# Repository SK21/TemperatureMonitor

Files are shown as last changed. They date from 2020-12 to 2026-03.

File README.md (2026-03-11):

# TemperatureMonitor

Temperature Monitor reads temperatures from DS18B20 sensors in grain bins. It consists of a server and multiple clients (controlboxes). The server is installed on a PC on the LAN. Each controlbox sends data over wifi to the server. On startup if a network connection can't be made a web page is started at 192.168.4.1 . 
  
Hookup Schematic:
 

TMarduino can use a DS2482 1-Wire Master. It is a device to connect to 1-Wire networks for improved performance. A DS2482 breakout is available at https://www.artekit.eu/products/breakout-boards/io/ak-ds2482s-100/

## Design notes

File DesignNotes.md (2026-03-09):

# BinTemps C# App - Design Notes

## Overview

A new C# desktop application to replace the VB6 server. Communicates over WiFi (UDP) with ESP8266-based bin temperature modules (existing TM13 hardware). Firmware is complete.

---

## Technology Stack

| Layer | Choice |
|---|---|
| UI | WinForms (.NET Framework 4.8) |
| Database | SQLite via EF6 (`EntityFramework` + `System.Data.SQLite`) |
| Charts | OxyPlot (`OxyPlot.WindowsForms`) |
| Network | UDP (`System.Net.Sockets.UdpClient`) |
| Async | async/await + CancellationToken |
| Config | Newtonsoft.Json |

---

## Project Structure

```
BinTempsApp/
├── BinTempsApp.slnx
└── BinTempsApp/
    ├── BinTempsApp.csproj        # .NET Framework 4.8 WinForms
    ├── Program.cs
    ├── MainForm.cs               # Main MDI or tabbed shell
    ├── Network/
    │   ├── UdpServer.cs          # Bind, heartbeat broadcast, receive loop
    │   └── PacketParser.cs       # Parse raw bytes into typed packets
    ├── Models/
    │   ├── Module.cs
    │   ├── Sensor.cs
    │   ├── TemperatureRecord.cs
    │   └── Packet.cs
    ├── Data/
    │   ├── AppDbContext.cs       # EF6 DbContext
    │   └── Migrations/
    ├── Services/
    │   ├── TemperatureService.cs
    │   └── SensorService.cs
    └── Forms/
        ├── DashboardForm.cs      # Live module/connection status
        ├── TemperatureForm.cs    # Temperature data sheet
        ├── ChartForm.cs          # OxyPlot trend charts
        ├── BinMapForm.cs         # Visual bin layout
        └── SettingsForm.cs       # App settings, sensor management
```

---

## UDP Protocol (PGNs)

All packets begin with two fixed bytes: type identifier and protocol version (120).
Temperature lo/hi = raw DS18B20 16-bit value (signed, divide by 16.0 for Celsius).

### App to Module

#### 30820 - Heartbeat (broadcast, 3 bytes)
| Byte | Value |
|---|---|
| 0 | 100 |
| 1 | 120 |
| 2 | CRC |

Sent by app on a regular interval (e.g. every 30 seconds) to the subnet broadcast address. Modules track the last heartbeat time. If no heartbeat is received for 90 seconds (~3 missed), the module attempts WiFi reconnect and re-announces itself with PGN 30831.

#### 30821 - Command (app to module)
| Byte | Field |
|---|---|
| 0 | 101 |
| 1 | 120 |
| 2 | Module ID (0x00 = global broadcast) |
| 3 | Command byte |
| 4 | CRC |

Command byte bits:
- bit 0 = send sensor temps (30830)
- bit 1 = send module description (30831)

Module ID 0x00 = global broadcast — all modules respond.
Module ID 0x01-0xFE = targeted, module responds immediately.
Module ID 0xFF = reserved.

#### 30822 - Set Module Description (app to module)
| Byte | Field |
|---|---|
| 0 | 102 |
| 1 | 120 |
| 2-7 | Module MAC (6 bytes, used to identify target) |
| 8 | New Module ID |
| 9-18 | New Description (10 bytes, UTF-8) |
| 19 | CRC |

#### 30823 - Set Sensor User Data (app to module)
| Byte | Field |
|---|---|
| 0 | 103 |
| 1 | 120 |
| 2 | Module ID |
| 3-10 | Sensor serial / ROM code (8 bytes) |
| 11 | New user data byte 0 |
| 12 | New user data byte 1 |
| 13 | CRC |

---

### Module to App

#### 30830 - Temperature Data
| Byte | Field |
|---|---|
| 0 | 110 |
| 1 | 120 |
| 2 | Module ID |
| 3-10 | Sensor serial / ROM code (8 bytes) |
| 11 | Temp lo (raw DS18B20 low byte) |
| 12 | Temp hi (raw DS18B20 high byte) |
| 13 | Sensor user data byte 0 |
| 14 | Sensor user data byte 1 |
| 15 | Count of sensors remaining |
| 16 | CRC |

One packet per sensor. Sensor user data (bin/cable/sensor encoding) is included inline with each reading. Count of sensors remaining decrements to 0 on the final packet.

#### 30831 - Module Description
| Byte | Field |
|---|---|
| 0 | 111 |
| 1 | 120 |
| 2 | Module ID (0 = unregistered) |
| 3-8 | Module MAC (6 bytes) |
| 9-18 | Module description (10 bytes, UTF-8) |
| 19-20 | InoID / firmware version (uint16, lo byte first) |
| 21 | CRC |

Sent unsolicited once on startup/reconnect. If module ID = 0, server knows it is unregistered and prompts user to assign an ID via 30822. Also sent in response to 30821 command bit 1. The InoID field allows the app to detect outdated firmware.

---

## Sensor User Data Encoding

16-bit value stored in DS18B20 EEPROM bytes 2-3 (unchanged from original firmware):
```
[15:8] = Bin ID    [7:4] = Cable ID    [3:0] = Sensor number
```

```csharp
public static (byte Bin, byte Cable, byte Sensor) DecodeUserData(ushort raw)
    => ((byte)(raw >> 8), (byte)((raw >> 4) & 0xF), (byte)(raw & 0xF));
```

---

## WiFi Provisioning

Modules are physically installed in the field (grain bins), often too far from the server PC to reliably connect to the module's soft-AP hotspot. Provisioning is therefore done via a smartphone brought to the bin.

### Provisioning Flow
1. Module boots with no stored credentials (or fails to connect after N attempts)
2. Module starts a soft-AP named `BinTemps-<MAC>` and serves a simple config web page
3. Technician walks to the bin with a smartphone, connects to the module's AP
4. Browser opens the config page, technician enters SSID + password
5. Module saves credentials to EEPROM and reboots into station mode
6. On reconnect, module sends unsolicited 30831 — the C# app handles registration from there

The C# app has no role in provisioning. It only becomes involved once the module is on the network.

---

## Module Identity & Discovery

- **MAC address** is the stable unique key for each module (factory-burned, never changes).
- **Module ID** (1 byte, 1-254) is assigned by the server via 30822 and stored in module EEPROM.
- **ID = 0** means unregistered.

### New Module Flow
1. Module powers up with ID = 0
2. Module sends one unsolicited 30831 (MAC + ID=0)
3. Server detects ID=0, prompts user to assign name/ID
4. Server sends 30822 using MAC as key, assigns new ID + description
5. Module stores ID in EEPROM, uses it from then on
6. If 30822 is lost, the next global 30821 (broadcast) will re-trigger the 30831 from the module

### Reconnect Flow
1. Module receives no heartbeat for 90 seconds
2. If WiFi is disconnected, module attempts reconnect
3. On reconnect, `udp.begin(port)` is called and module sends unsolicited 30831 (with its assigned ID)
4. If WiFi is still connected but server went quiet, module re-sends 30831 to re-announce itself
5. Server knows the module is back online

---

## Database Schema (SQLite)

```
Modules      - MacAddress (PK), ModuleId, Name, LastKnownIp, LastSeen, Status
Sensors      - RomCode (PK), ModuleMac (FK), BinId, CableId, SensorNum, Enabled, Offset, MaxTemp, Label
Records      - Id, RomCode (FK), Temperature, Timestamp
Bins         - Id, Name, Description, Rows, Cols
BinSensorMap - BinId, SensorRomCode, Row, Col
Settings     - Key, Value
```

---

## C# App — UDP Notes

- App binds to `0.0.0.0` on port 1600 to receive UDP from any module on the network
- Heartbeat (30820) and commands (30821) are sent to the subnet broadcast address
- Module responses (30830, 30831) arrive from the module's IP — use `UdpReceiveResult.RemoteEndPoint` to track module IPs
- `UdpClient` must have `EnableBroadcast = true` and `Client.SetSocketOption(SocketOptionLevel.Socket, SocketOptionName.ReuseAddress, true)`
- Since modules broadcast their responses, the app may receive its own sent packets — filter by checking the source IP is not the local machine

## Implementation Phases

1. **Phase 1** *(start here)* — `UdpServer` (bind, broadcast heartbeat, receive loop), `PacketParser` with unit tests, console test harness against real hardware
2. **Phase 2** — EF Core models (`AppDbContext`, migrations), `TemperatureService`, `SensorService`
3. **Phase 3** — Main WPF window, Dashboard (live module list, online/offline status), Temperature sheet
4. **Phase 4** — Chart view, Bin map, CSV export
5. **Phase 5** — Settings UI, Sensor management (assign bin/cable/sensor), Installer

---

## Open Questions / Future Considerations

- Add full timestamp (hour/min/date) to heartbeat 30820 if modules ever need to self-timestamp queued data while server is offline
- ACK/NAK response from module for 30822/30823 write commands (not yet defined)
- Error/diagnostic reporting PGN (1-Wire bus failures, CRC error counts, WiFi RSSI)
- OTA firmware update PGN

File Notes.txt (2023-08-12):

Connect to the module hotspot and open url 192.168.4.1 to change settings.

Parasitic mode will only work with genuine DS18B20 temperature sensors. Powered mode needs to be used otherwise. Yellow signal, red power, black ground.

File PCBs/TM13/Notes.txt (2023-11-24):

Put jumpers on Signal to DS9503P for input protection. To bypass input protection put jumpers on Signal to DS2482S.

The one-wire bus can be read with the DS2482S or just using GPIO 12.

Antenna example:

https://www.amazon.ca/Bingfu-Pigtail-Standard-Satellite-SiriusXM/dp/B00VE1XH4A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

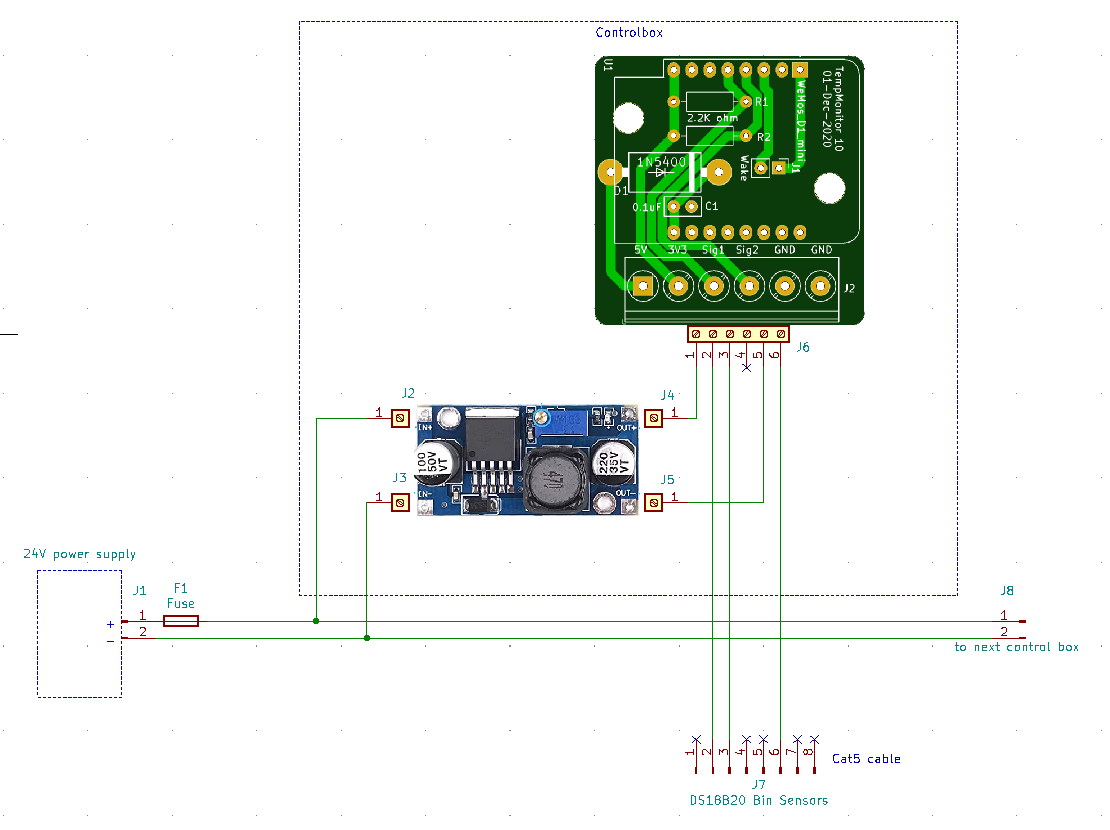
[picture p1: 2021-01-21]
Current Files/PCBs/TM10_PCB/TempMon_Hookup/Hookup schematic.PNG

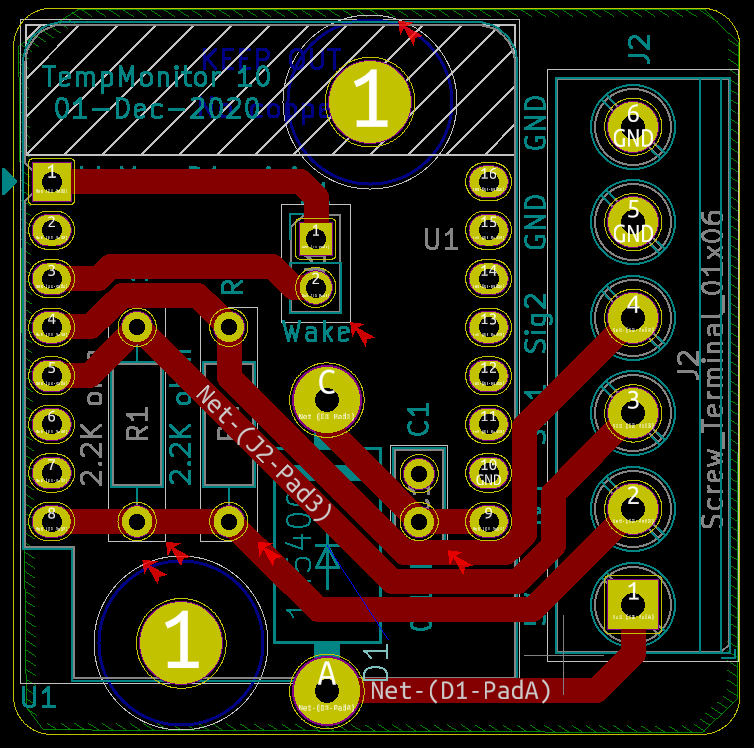
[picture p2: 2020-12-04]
Current Files/PCBs/TM10_PCB/pcb.PNG

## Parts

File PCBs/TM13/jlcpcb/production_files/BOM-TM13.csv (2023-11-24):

Comment | Designator | Footprint | LCSC
1N4007 | D2 | D_SMA | C111122
SS36 | D3 | SMA(DO-214AC) | C116712
DS2482S-100+T&R | U3 | 21-0041B_8_MXM | C143306
10uF | C1,C7 | C_0805_2012Metric | C15850
Barrel_Jack_Switch | J4 | BarrelJack_Wuerth_6941xx301002 | C16214
1K | R11,R13 | R_0603_1608Metric | C21190
341 | R10,R9 | R_0603_1608Metric | C23138
BSS138 | Q1,Q2 | SOT-23 | C255592
10K | R1,R2,R5,R6 | R_0603_1608Metric | C25804
217 | R3,R4,R8 | R_0603_1608Metric | C25811
330uF | C10 | CP_Elec_10x10.5 | C280411
1uF | C5,C8 | C_0805_2012Metric | C28323
C2935469 | F1 | Fuse_Holder_C2935469 | C2935469
470uF | C9 | CP_Elec_10x10.5 | C310845
PCA9306DCUR | IC1 | PCA9306DCUR | C33196
2.2K | R12,R7 | R_0603_1608Metric | C4190
KF142V-5.0-4P | KF1,KF2 | KF142V-5.08-4P | C475136
Conn_01x03_Male | J2,J3 | PinHeader_1x03_P2.54mm_Vertical | C49257
0.1uF | C2,C3,C4 | C_0805_2012Metric | C49678
BC847 | Q3 | SOT-23 | C57668
105133-0011 | J5 | MOLEX_105133-0011 | C586226
22uF | C6 | C_0805_2012Metric | C602037
XL2596 | IC3 | TO263-5L | C74190
ESP-07 | U1 | ESP-07S | C82895
LED | D4 | LED_0805_2012Metric | C84256
CH340C | U2 | SOIC-16_3.9x9.9mm_P1.27mm | C84681
BSS841 | Q4 | SOT-23 | C8492
DS9503P | U4 | TSO6C | C879660
AZ1117 | IC2 | SOT230P700X180-4N | C92517
SMDRI127-330MT | L1 | TMPA1265SP-101MN-D | C9400

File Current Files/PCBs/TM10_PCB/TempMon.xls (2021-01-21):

Index | Description | Quantity | Unit Price | Total | Order | on hand | Part Number | location
1 | 0.1uF capacitor | 1 | $0.68 | $0.68 |  |  | C320C104J5R5TA | https://www.mouser.ca/ProductDetail/KEMET/C320C104J5R5TA7301
2 | power supply | 1 | $1.90 | $1.90 |  |  |  | https://www.amazon.ca/gp/product/B07JNQFV7F/ref=ox_sc_act_title_1?smid=ACU1OE3CHQ5IP&psc=1
3 | 2.2K ohm resistor | 3 | $0.19 | $0.57 |  |  |  | https://www.mouser.ca/ProductDetail/Yageo/CFR-50JT-52-2K2?qs=KUIzHt%2Fe91mnLDsXm5x8LA%3D%3D
4 | Diode | 1 | $0.59 | $0.59 |  |  | 1N5401RLG | https://www.mouser.ca/ProductDetail/ON-Semiconductor/1N5401RLG?qs=y2kkmE52mdOxhusEL9Va0w%3D%3D
5 | 2 pin screw terminal, 5mm | 3 | $0.62 | $1.86 |  |  | 1935161 | https://www.mouser.ca/ProductDetail/Phoenix-Contact/1935161?qs=W3wJikR1%252BS6eKzfFl8Rbew==
6 | PCB | 1 | $0.75 | $0.75
7 | enclosure | 1 | $9.81 | $9.81 |  |  | NBF-32004 | https://www.mouser.ca/ProductDetail/563-PN-1321-DGMB
8 | 2 pin header | 1 | $0.03 | $0.03 |  |  |  | https://www.amazon.ca/Gikfun-Breakable-Header-2-54mm-Arduino/dp/B01LYYUSOH
9 | Wemos D1 min | 1 | $6.00 | $6.00 |  |  |  | https://www.universal-solder.ca/product/esp-01-wifi-module-esp8266-1mb-internet-of-things/
 |  |  |  | $22.19

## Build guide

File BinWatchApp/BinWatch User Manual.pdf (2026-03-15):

# BinWatch User Manual

BinWatch monitors grain bin temperatures using ESP8266-based sensor modules (BinTempsModule). Each module reads DS18B20 temperature sensors on 1-Wire buses and reports readings over WiFi/UDP to the BinWatch desktop application. Temperatures are stored in a local database and displayed in real time.

## Table of Contents

1. Starting the App
2. Dashboard
3. Temperatures Tab
4. History Tab
5. Settings
6. Sensor Modules – First-time Setup
7. Sensor Modules – Settings Page
8. Temperature Update Schedule
9. Firmware Update – Initial Upload
10. Firmware Update – OTA
11. Errors and Logging
12. File Summary

## 1. Starting the App

Run BinWatch.exe. On first run it creates BinWatch.db alongside the exe. The status bar shows the UDP port the app is listening on.

The app has three tabs:

Tab | Purpose
Dashboard | Lists all known modules and their status
Temperatures | Shows the latest reading per sensor
History | Chart of historical readings for a selected sensor
BinWatch User Manual | file:///D:/Sync/BinTemps/User%20Manual/UserManual.html
1 of 6 | 3/15/2026, 10:44 AM

## 2. Dashboard

Modules appear automatically when they announce themselves over the network. Each row shows the module name, ID, IP address, status, last-seen time, and firmware version.

Button | Action
Update Temperatures | Requests a fresh sensor read from the selected module immediately
Identify Module | Requests the module to re-announce its name and ID
Discover Modules | Broadcasts a discovery request — all modules on the network respond immediately
Settings | Configure the database path and passive mode (see Settings)
Convert Sensors | Remap sensor user-data bytes to bin/cable/sensor numbers

Double-click a module row to edit its name and ID.

## 3. Temperatures Tab

Shows the most recent temperature for each known sensor. Columns include bin, cable, sensor number, label, temperature, and timestamp.

Double-click a row to edit sensor settings:

Field | Description
Label | Custom name for the sensor
Max temperature | Alarm threshold — rows exceeding this value are highlighted
Offset | Calibration offset added to the raw reading
Enabled | Untick to hide this sensor from the display

## 4. History Tab

Select a sensor from the dropdown, set the date range, and click Load. The chart loads automatically each time you switch to this tab.

## 5. Settings

Dashboard toolbar > Settings

Setting | Description
Database path | Where BinWatch.db is stored. Leave blank to use the default (same folder as the exe). Restart the app to apply a path change.
Passive mode | Tick to open an existing database read-only without starting the UDP server. Use this on a secondary machine sharing a database over a network drive.
Debug logging | Tick to write verbose debug output to BinWatch.log . Takes effect immediately without a restart.

## 6. Sensor Modules – First-time Setup

Each module broadcasts a WiFi access point named ModuleName (MAC). Connect to it with any device and open a browser.

- Default gateway IP: 192.168.4.1

The module's home page shows the module name and sensor count, with links to:

Link | Purpose
Temperatures | View current readings on the module
Settings | Configure WiFi, module name, and hardware options
Refresh | Trigger an immediate temperature read

## 7. Sensor Modules – Settings Page

Field | Description
Network / Password | WiFi network the module connects to for UDP reporting
Module Name | Shown in BinWatch (max 10 characters)
Use WiFi Server | Tick to enable WiFi connection; untick to run in access-point mode only
Use DS2482 | Tick if the module uses a DS2482 I²C 1-Wire master instead of GPIO
Strong pullup | Tick if a strong pullup circuit is fitted

Click Save/Restart — the module restarts automatically with the new settings.

The bottom of the page shows the current WiFi connection status, signal strength, and firmware version. An Update Firmware link opens the OTA update page directly.

The module ID and name are normally set from BinWatch using Identify Module, then double-clicking the module row.

## 8. Temperature Update Schedule

Each module reads and reports temperatures once per hour. To reduce network congestion, modules stagger their reports based on their ID:

- Module 1 reports at the top of the hour
- Module 2 reports 1 minute later
- Module 3 reports 2 minutes later, and so on

BinWatch also sends a broadcast poll every 60 minutes as a fallback. Each module staggers its response by 1 minute per module ID — module 1 responds immediately, module 2 after 1 minute, module 3 after 2 minutes, and so on.

## 9. Firmware Update – Initial Upload

A blank ESP8266 has no firmware and cannot use OTA. The first upload must be done using the Arduino IDE with a USB cable connected to the module:

1. Install the Arduino IDE and add ESP8266 board support via File > Preferences > Additional Board URLs:

http://arduino.esp8266.com/stable/package_esp8266com_index.json
2. Open the BinTempsModule sketch (the | .ino | source files — not the | .bin | ).
3. Select the correct board (LOLIN(Wemos) D1 R2 & mini or NodeMCU 1.0) and the COM port.
4. Click Upload. Once complete the module restarts and its WiFi access point becomes visible.

Subsequent updates can be done wirelessly using OTA (see below).

## 10. Firmware Update – OTA

The firmware file BinTempsModule.ino.bin is located in this folder alongside BinWatch.exe.

1. Connect your computer to the module's WiFi access point (ModuleName (MAC)), or ensure you are on the same network if the module is already connected via WiFi.
2. Open a browser and navigate to the module's IP address followed by | /update | :
- Via access point: | http://192.168.4.1/update
- Via WiFi network: | http://<module-ip>/update
3. The OTA update page will appear. Click Choose File, select BinTempsModule.ino.bin, then click Update.
4. Wait for the progress bar to complete. The module restarts automatically with the new firmware.
5. Verify the update by checking the firmware version shown in BinWatch's Dashboard tab. The version is in DDMMY format — DD = day, MM = month, Y = last digit of the year (e.g. 10036 = 10th March 2026).

Note: After a firmware update that changes the module's data structure, the module reloads its default hardware settings. WiFi credentials are stored separately and are not affected. Re-enter the module name and hardware options (DS2482, strong pullup) via the Settings page if needed.

## 11. Errors and Logging

BinWatch logs errors and key events to BinWatch.log in the same folder as the exe. A backup copy is kept as BinWatch.log.bak when the log exceeds 1 MB. Check this file if the app behaves unexpectedly.

## 12. File Summary

File | Description
BinWatch.exe | Main application
BinWatch.db | SQLite database (modules, sensors, temperature history)
BinWatch.ini | App settings (database path, passive mode, window position)
BinWatch.log | Error and event log
BinTempsModule.ino.bin | Sensor module firmware binary for OTA updates

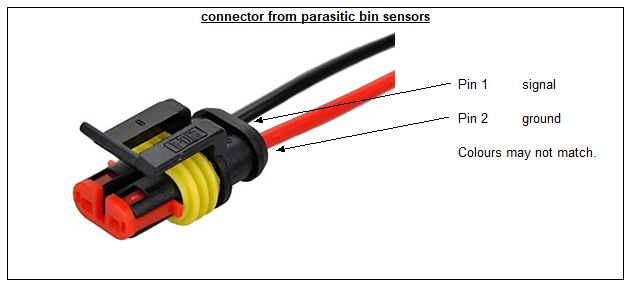
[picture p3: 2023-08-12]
bin sensor wiring.PNG

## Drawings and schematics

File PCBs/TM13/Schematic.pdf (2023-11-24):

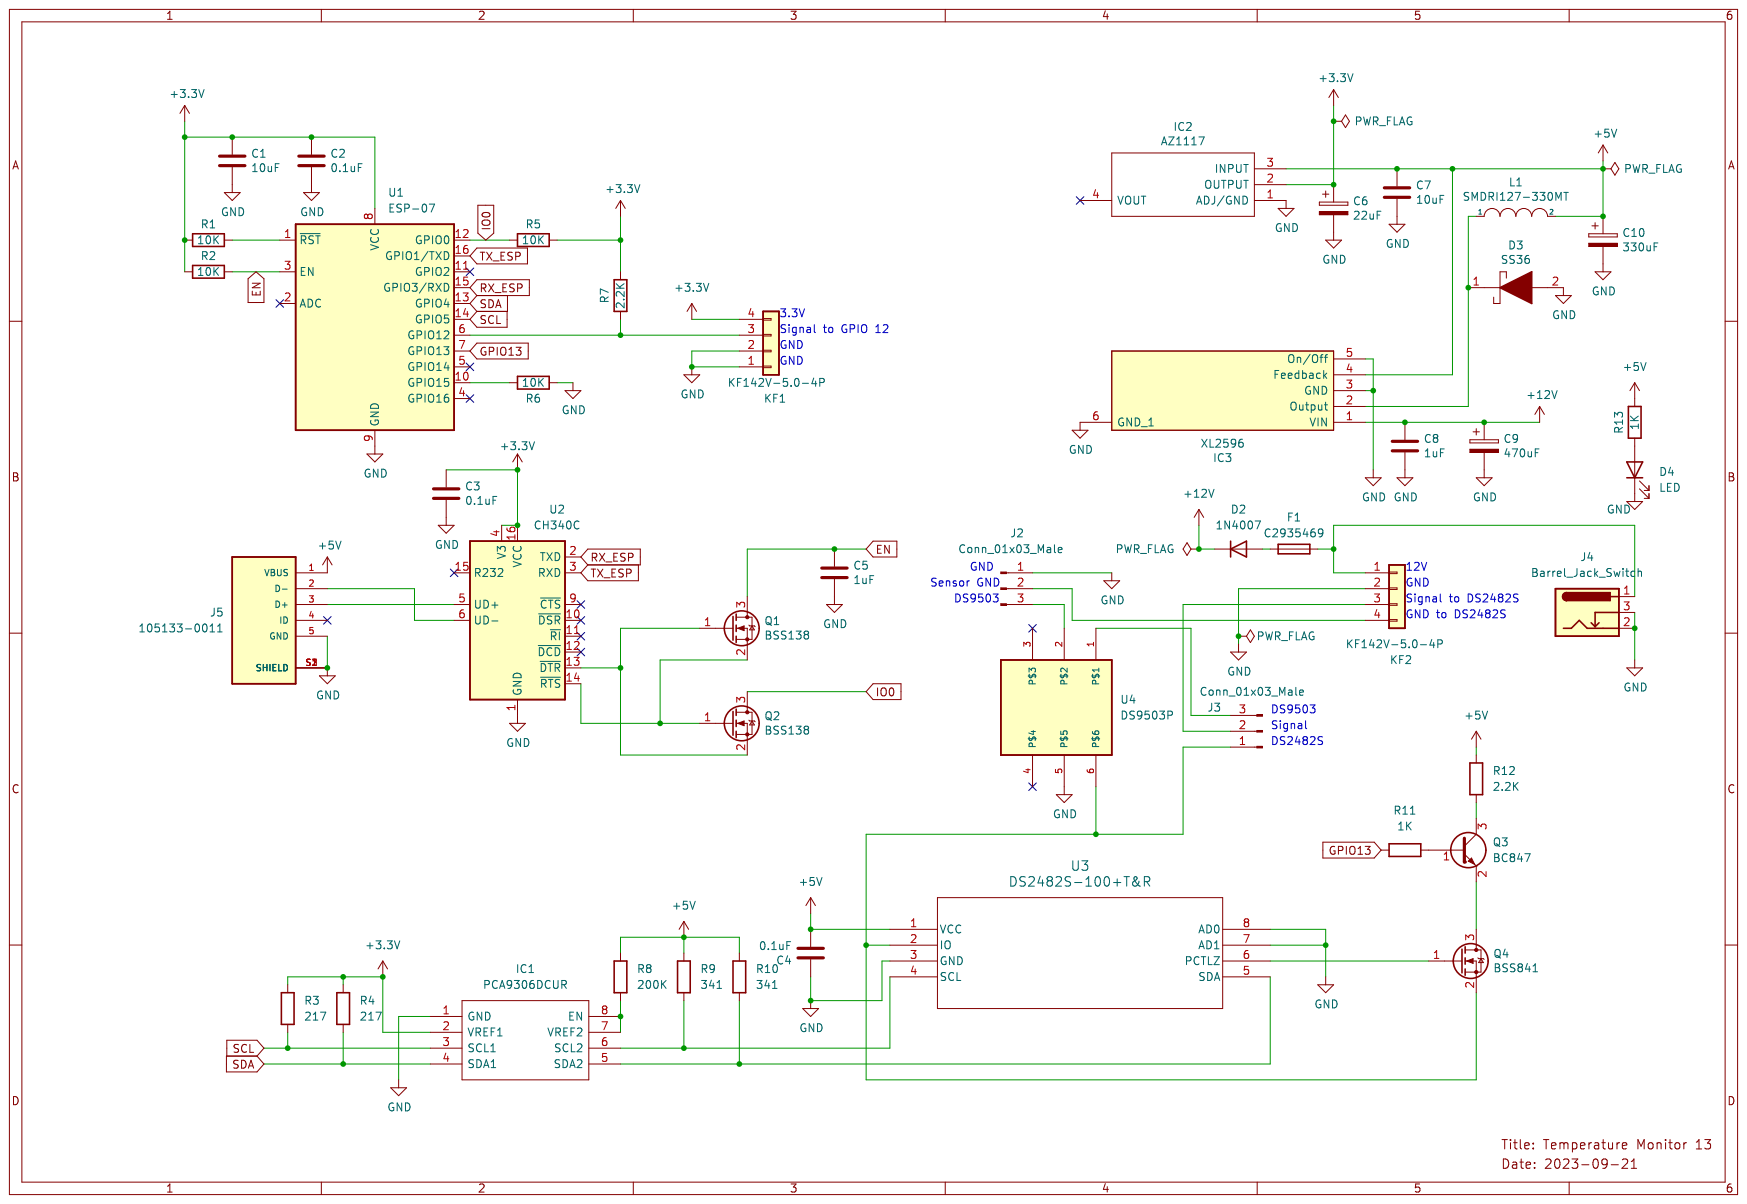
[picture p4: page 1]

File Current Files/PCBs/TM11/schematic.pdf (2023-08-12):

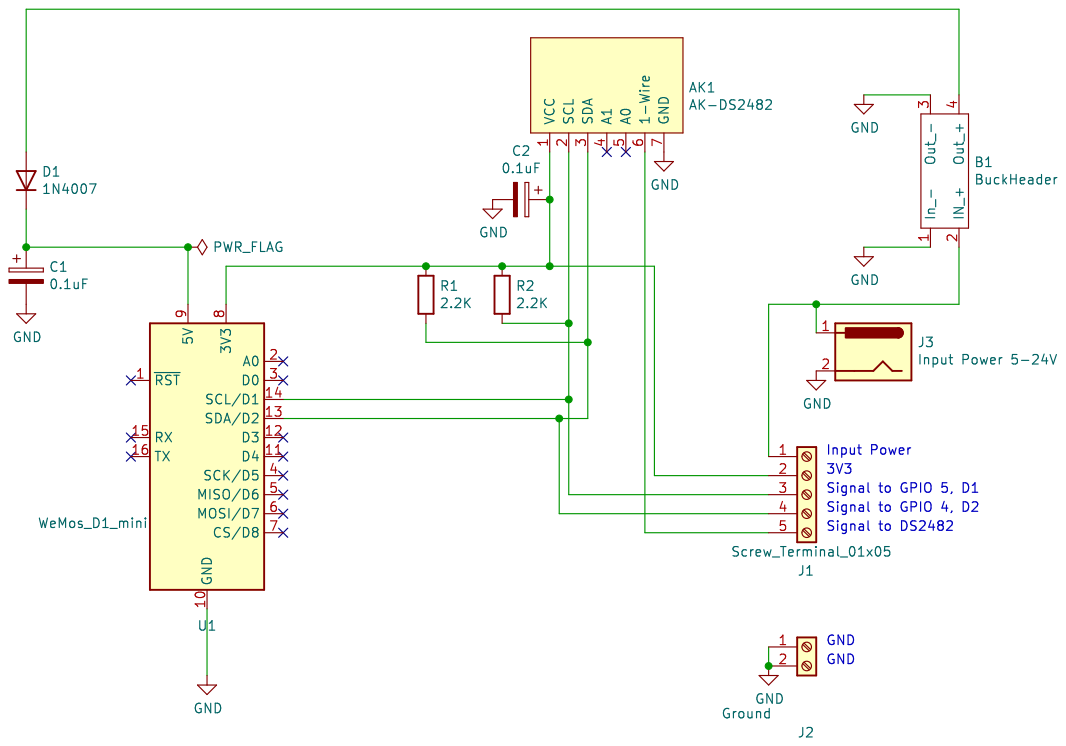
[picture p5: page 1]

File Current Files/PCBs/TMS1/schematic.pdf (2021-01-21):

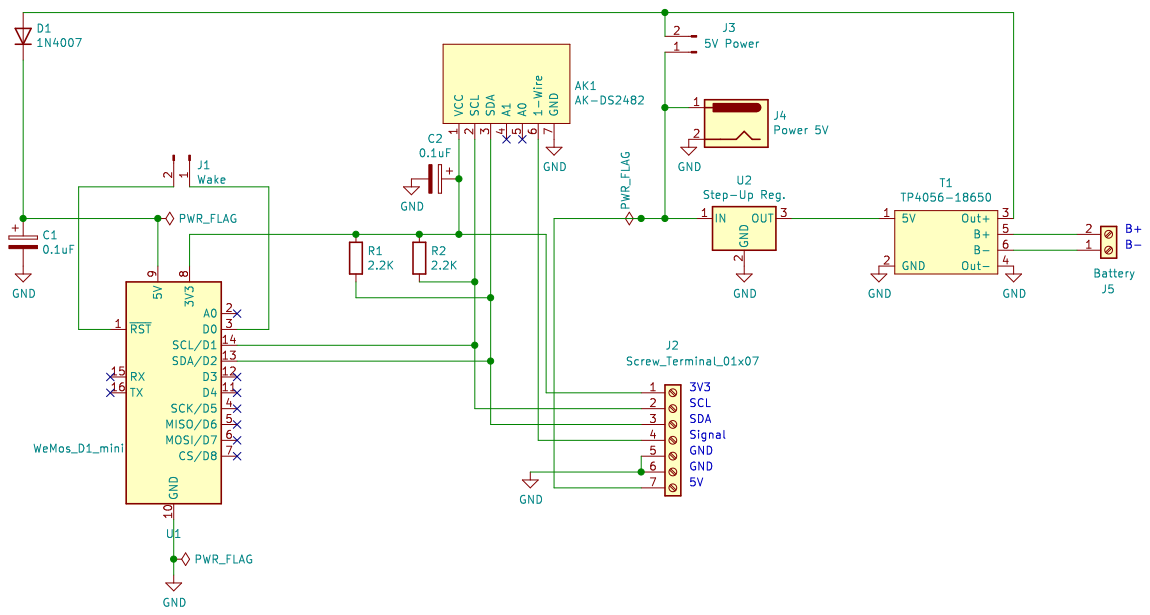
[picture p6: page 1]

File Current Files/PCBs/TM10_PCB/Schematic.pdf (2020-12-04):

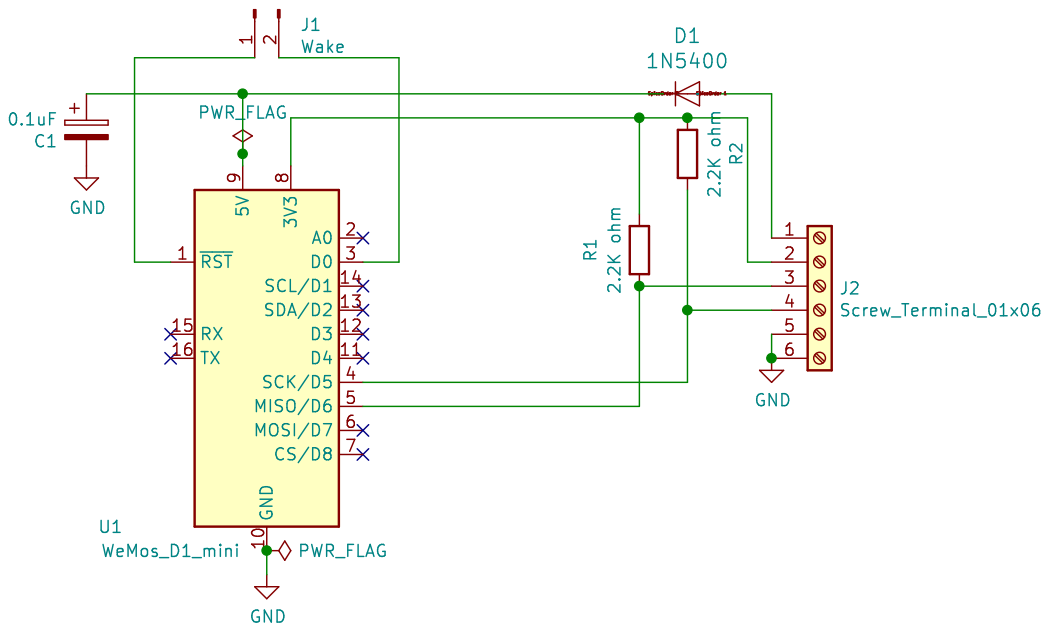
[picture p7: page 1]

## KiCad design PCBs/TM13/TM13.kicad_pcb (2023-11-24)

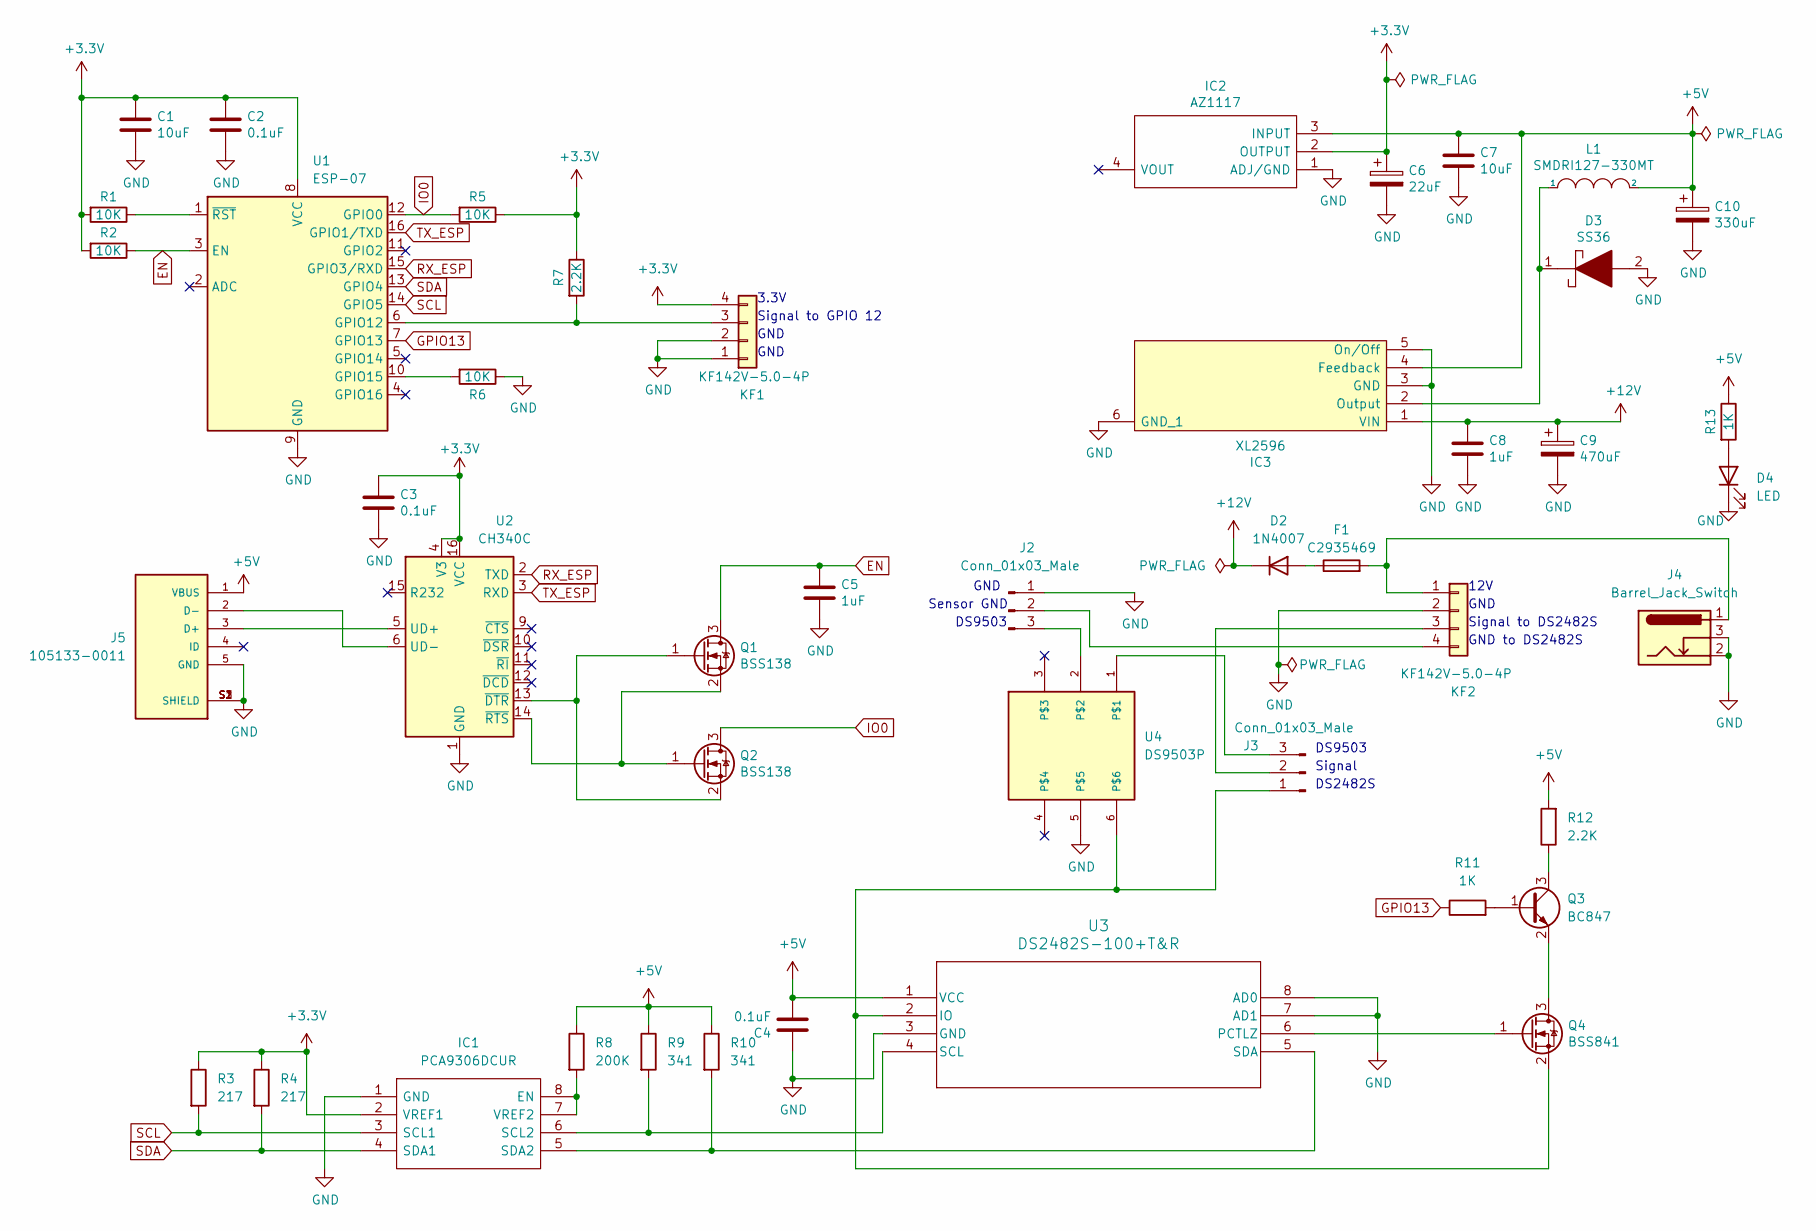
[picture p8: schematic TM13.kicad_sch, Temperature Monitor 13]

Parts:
C1, C7: 10uF; C_0805_2012Metric
C2, C3, C4: 0.1uF; C_0805_2012Metric
C5, C8: 1uF; C_0805_2012Metric
C6: 22uF; C_0805_2012Metric
C9: 470uF; CP_Elec_10x10.5
C10: 330uF; CP_Elec_10x10.5
D2: 1N4007; D_SMA
D3: SS36; SMA(DO-214AC)
D4: LED; LED_0805_2012Metric
F1: C2935469; Fuse_Holder_C2935469
IC1: PCA9306DCUR; Mouser Part Number 595-PCA9306DCUR
IC2: AZ1117; SOT230P700X180-4N; Mouser Part Number 621-AZ1117CH-3.3TRG1
IC3: XL2596; TO263-5L
J2, J3: Conn_01x03_Male; PinHeader_1x03_P2.54mm_Vertical
J4: Barrel_Jack_Switch; BarrelJack_Wuerth_6941xx301002
J5: 105133-0011; MOLEX_105133-0011; PARTREV C
KF1, KF2: KF142V-5.0-4P; KF142V-5.08-4P
L1: SMDRI127-330MT; TMPA1265SP-101MN-D
Q1, Q2: BSS138; SOT-23
Q3: BC847; SOT-23
Q4: BSS841; SOT-23
R1, R2, R5, R6: 10K; R_0603_1608Metric
R3, R4: 217; R_0603_1608Metric
R7, R12: 2.2K; R_0603_1608Metric
R8: 200K; R_0603_1608Metric
R9, R10: 341; R_0603_1608Metric
R11, R13: 1K; R_0603_1608Metric
U1: ESP-07; ESP-07S
U2: CH340C; SOIC-16_3.9x9.9mm_P1.27mm
U3: DS2482S-100+T&R; 21-0041B_8_MXM
U4: DS9503P; TSO6C

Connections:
+3.3V: C1.1, C2.1, C3.1, C6.1, IC1.2 (VREF1), IC2.2 (OUTPUT), KF1.4, R1.2, R2.2, R3.1, R4.1, R5.1, R7.1, U1.8 (VCC), U2.4 (V3), U2.16 (VCC)
+5V: C4.2, C7.1, C10.1, IC2.3 (INPUT), IC3.4 (Feedback), J5.1 (VBUS), L1.2, R8.1, R9.1, R10.1, R12.2, R13.1, U3.1 (VCC)
+12V: C8.1, C9.1, D2.1 (K), IC3.1 (VIN)
EN: C5.1, Q1.3 (D), R2.1, U1.3 (EN)
GND: C1.2, C2.2, C3.2, C4.1, C5.2, C6.2, C7.2, C8.2, C9.2, C10.2, D3.2, D4.1 (K), IC1.1 (GND), IC2.1 (ADJ/GND), IC3.3 (GND), IC3.5 (On/Off), IC3.6 (GND_1), J2.1, J4.2, J4.3, J5.5 (GND), J5.S1 (SHIELD), J5.S2 (SHIELD), J5.S3 (SHIELD), KF1.1, KF1.2, KF2.2, R6.1, U1.9 (GND), U2.1 (GND), U3.3 (GND), U3.7 (AD1), U3.8 (AD0), U4.5
GPIO13: R11.1, U1.7 (GPIO13)
IO0: Q2.3 (D), R5.2, U1.12 (GPIO0)
unnamed: D2.2 (A), F1.1
unnamed: D4.2 (A), R13.2
unnamed: IC1.7 (VREF2), IC1.8 (EN), R8.2
unnamed: IC1.6 (SCL2), R9.2, U3.4 (SCL)
unnamed: IC1.5 (SDA2), R10.2, U3.5 (SDA)
unnamed: D3.1, IC3.2 (Output), L1.1
unnamed: J2.2, KF2.4
unnamed: J2.3, U4.2
unnamed: J3.1, Q4.2 (S), U3.2 (IO), U4.6
unnamed: J3.2, KF2.3
unnamed: J3.3, U4.1
unnamed: J5.3 (D+), U2.5 (UD+)
unnamed: J5.2 (D-), U2.6 (UD-)
unnamed: KF1.3, R7.2, U1.6 (GPIO12)
unnamed: F1.2, J4.1, KF2.1
unnamed: Q1.1 (G), Q2.2 (S), U2.13 (~DTR)
unnamed: Q1.2 (S), Q2.1 (G), U2.14 (~RTS)
unnamed: Q3.1 (B), R11.2
unnamed: Q3.3 (C), R12.1
unnamed: Q3.2 (E), Q4.3 (D)
unnamed: Q4.1 (G), U3.6 (PCTLZ)
unnamed: R6.2, U1.10 (GPIO15)
unnamed: R1.1, U1.1 (~RST)
RX_ESP: U1.15 (GPIO3/RXD), U2.2 (TXD)
SCL: IC1.3 (SCL1), R3.2, U1.14 (GPIO5)
SDA: IC1.4 (SDA1), R4.2, U1.13 (GPIO4)
TX_ESP: U1.16 (GPIO1/TXD), U2.3 (RXD)

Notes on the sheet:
Signal to DS2482S
Sensor GND
GND
DS9503
DS2482S
Signal
12V
GND to DS2482S
Signal to GPIO 12
3.3V

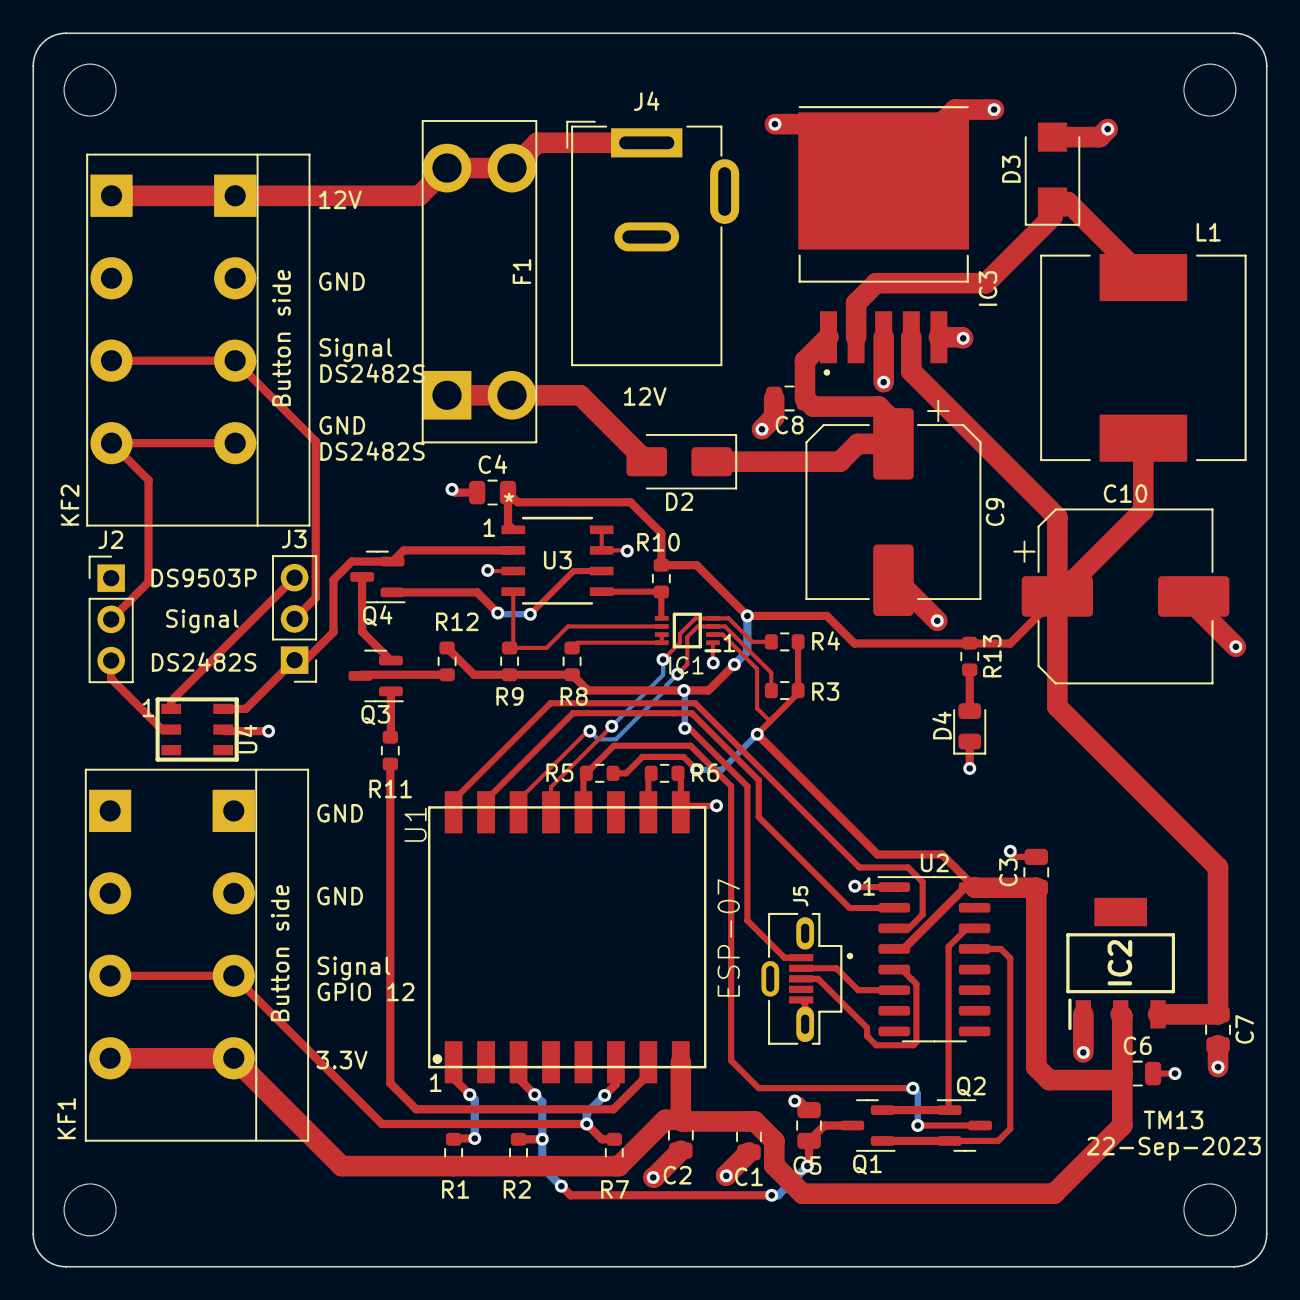
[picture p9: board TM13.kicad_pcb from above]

Board: 2 copper layers, 76.0 x 76.0 mm, 45 parts (0 on the bottom side), 34 nets.

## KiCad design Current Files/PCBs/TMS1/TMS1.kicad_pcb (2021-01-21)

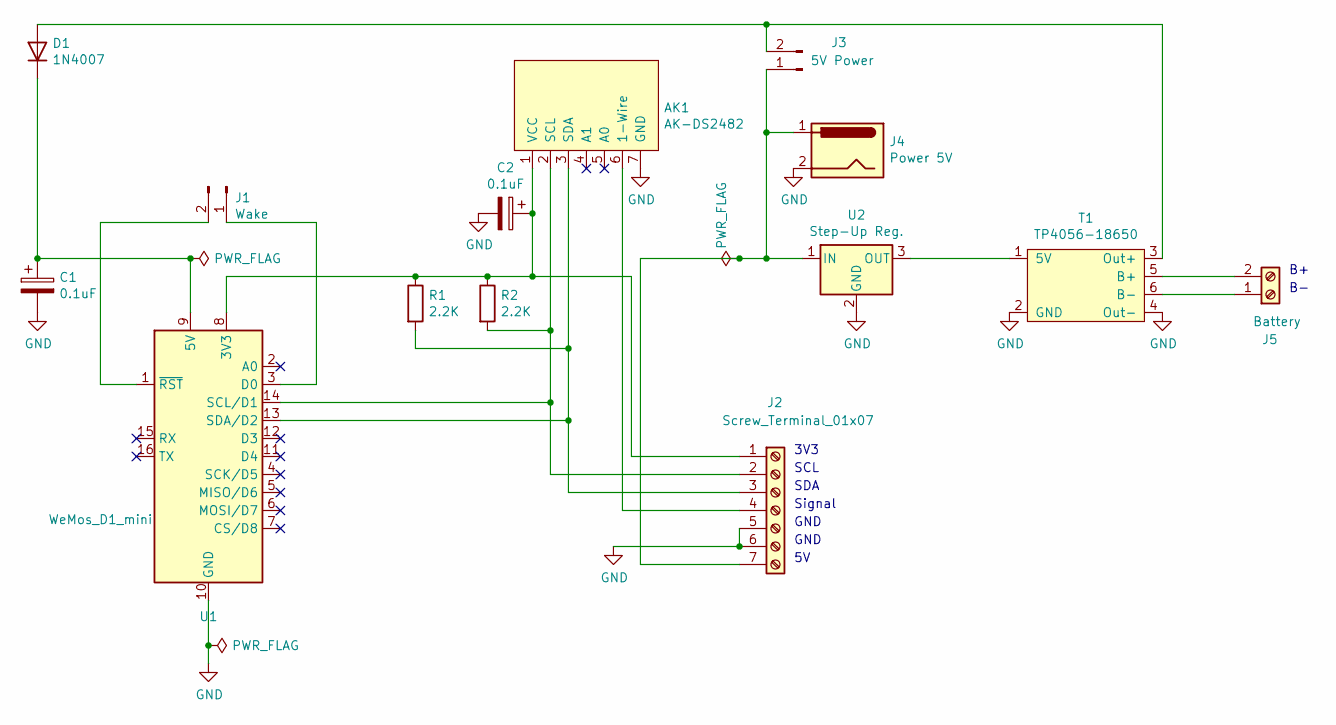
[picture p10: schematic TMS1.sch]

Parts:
AK1: AK-DS2482
C1, C2: 0.1uF; C_Disc_D5.0mm_W2.5mm_P2.50mm
D1: 1N4007; D_DO-41_SOD81_P10.16mm_Horizontal
J1: Wake; PinHeader_1x02_P2.54mm_Vertical
J2: Screw_Terminal_01x07; TerminalBlock_Phoenix_PT-1,5-7-5.0-H_1x07_P5.00mm_Horizontal
J3: 5V Power; PinHeader_1x02_P2.54mm_Vertical
J4: Power 5V; Uxcell_DC_power_jack
J5: Battery; TerminalBlock_Phoenix_PT-1,5-2-5.0-H_1x02_P5.00mm_Horizontal
R1, R2: 2.2K; R_Axial_DIN0207_L6.3mm_D2.5mm_P10.16mm_Horizontal
T1: TP4056-18650
U1: WeMos_D1_mini; WEMOS_D1_mini_light
U2: Step-Up Reg.; mEZD71201A

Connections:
GND: AK1.7 (GND), C1.2, C2.2, J2.5, J2.6, J4.2, T1.2 (GND), T1.4 (Out-), U1.10 (GND), U2.2 (GND)
unnamed: AK1.1 (VCC), C2.1, J2.1, R1.1, R2.1, U1.8 (3V3)
unnamed: AK1.2 (SCL), J2.2, R2.2, U1.14 (SCL/D1)
unnamed: AK1.3 (SDA), J2.3, R1.2, U1.13 (SDA/D2)
unnamed: AK1.6 (1-Wire), J2.4
unnamed: C1.1, D1.1 (K), U1.9 (5V)
unnamed: D1.2 (A), J3.2, T1.3 (Out+)
unnamed: J1.1, U1.3 (D0)
unnamed: J1.2, U1.1 (~RST)
unnamed: J2.7, J3.1, J4.1, U2.1 (IN)
unnamed: J5.1, T1.6 (B-)
unnamed: J5.2, T1.5 (B+)
unnamed: T1.1 (5V), U2.3 (OUT)

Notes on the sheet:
GND
Signal
SDA
SCL
3V3

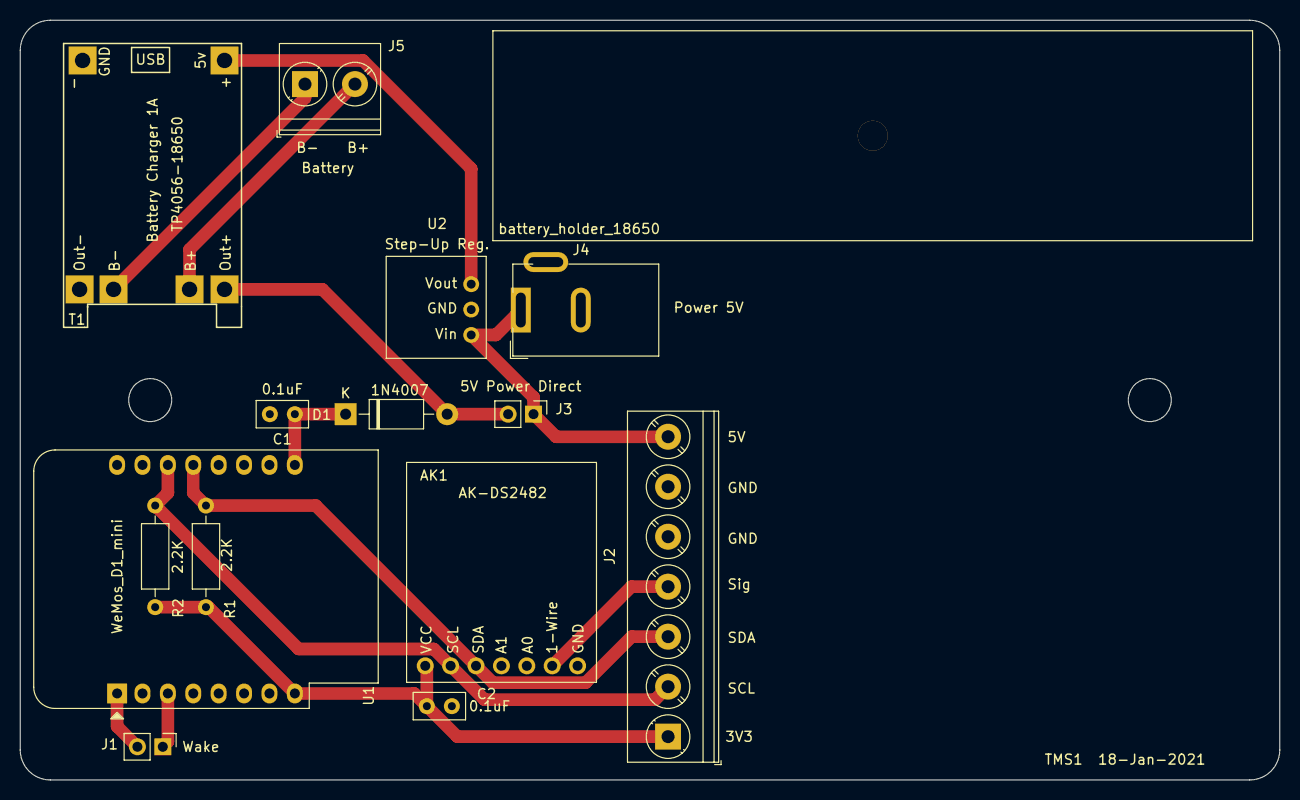
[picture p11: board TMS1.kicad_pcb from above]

Board: 2 copper layers, 126.0 x 76.0 mm, 17 parts (0 on the bottom side), 13 nets.

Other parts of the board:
 : MountingHole_4.3mm_M4
 #2: MountingHole_4.3mm_M4
 #3: battery_holder_18650

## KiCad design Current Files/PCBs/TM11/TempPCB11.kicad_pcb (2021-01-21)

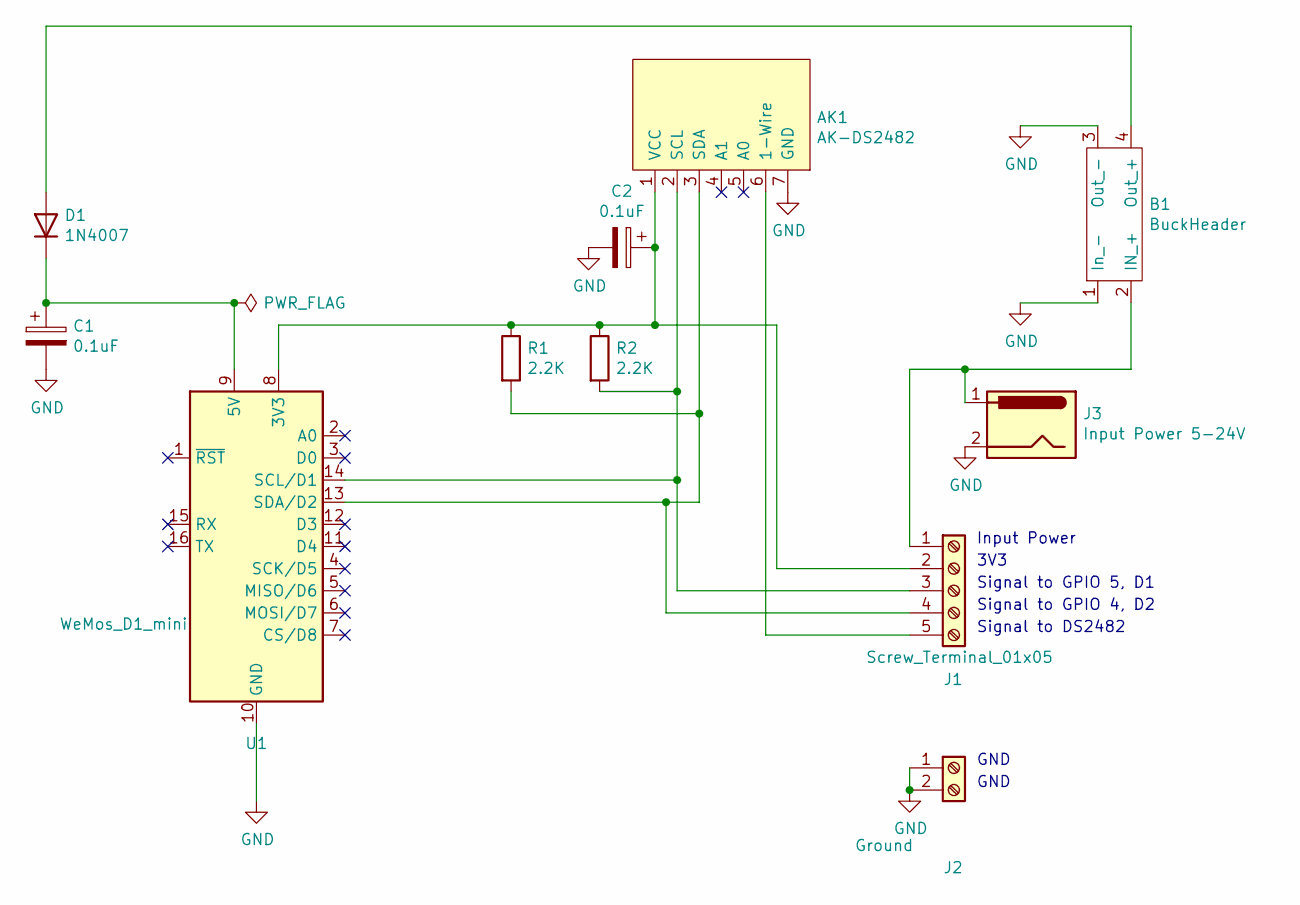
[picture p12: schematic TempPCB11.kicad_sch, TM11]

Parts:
AK1: AK-DS2482
B1: BuckHeader; LM2596_Buck_Header
C1, C2: 0.1uF; C_Disc_D5.0mm_W2.5mm_P2.50mm
D1: 1N4007; D_DO-41_SOD81_P10.16mm_Horizontal
J1: Screw_Terminal_01x05; TerminalBlock_Phoenix_PT-1,5-5-5.0-H_1x05_P5.00mm_Horizontal
J2: Ground; TerminalBlock_Phoenix_PT-1,5-2-5.0-H_1x02_P5.00mm_Horizontal
J3: Input Power 5-24V; Uxcell_DC_power_jack
R1, R2: 2.2K; R_Axial_DIN0207_L6.3mm_D2.5mm_P10.16mm_Horizontal
U1: WeMos_D1_mini; WEMOS_D1_mini_light

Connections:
GND: AK1.7 (GND), B1.1 (In_-), B1.3 (Out_-), C1.2, C2.2, J2.1, J2.2, J3.2, U1.10 (GND)
unnamed: AK1.1 (VCC), C2.1, J1.2, R1.1, R2.1, U1.8 (3V3)
unnamed: AK1.2 (SCL), J1.3, R2.2, U1.14 (SCL/D1)
unnamed: AK1.3 (SDA), J1.4, R1.2, U1.13 (SDA/D2)
unnamed: AK1.6 (1-Wire), J1.5
unnamed: B1.2 (IN_+), J1.1, J3.1
unnamed: B1.4 (Out_+), D1.2 (A)
unnamed: C1.1, D1.1 (K), U1.9 (5V)

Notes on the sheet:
3V3
Signal to GPIO 5, D1
Signal to GPIO 4, D2
Signal to DS2482
GND
Input Power

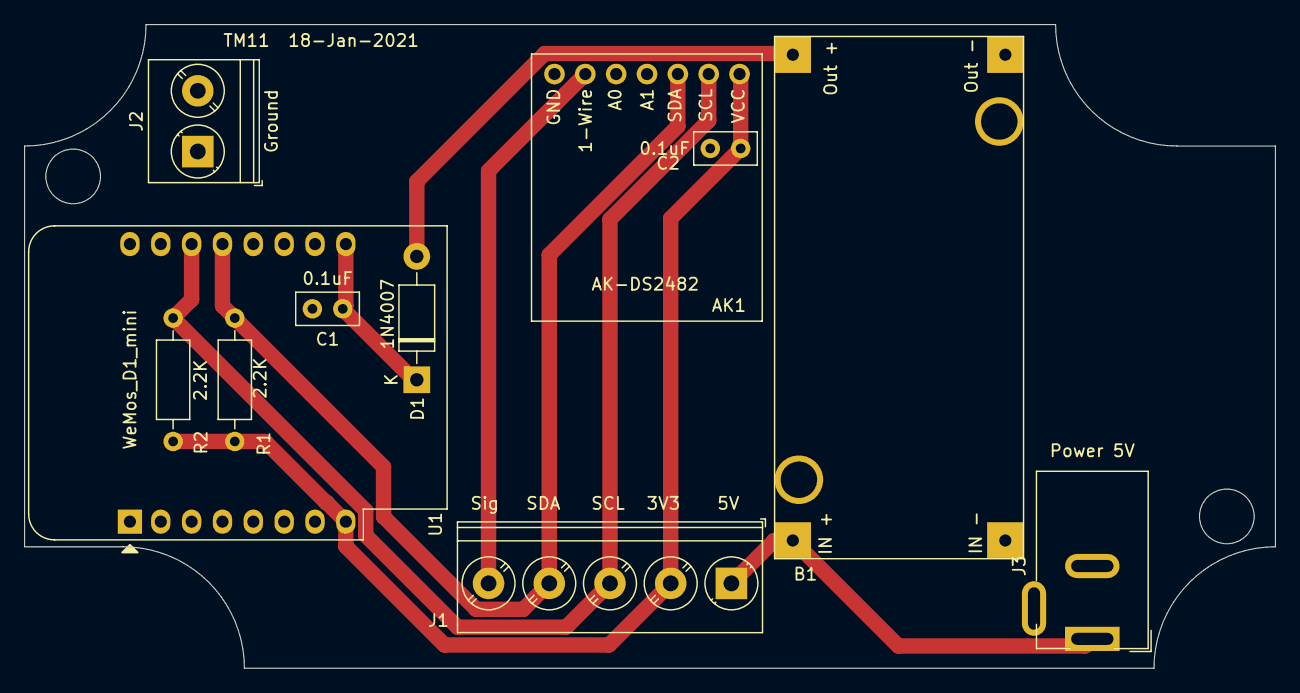
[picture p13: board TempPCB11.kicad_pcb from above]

Board: 2 copper layers, 103.0 x 53.0 mm, 13 parts (0 on the bottom side), 8 nets.

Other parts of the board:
 : MountingHole_3.2mm_M3
 #2: MountingHole_3.2mm_M3

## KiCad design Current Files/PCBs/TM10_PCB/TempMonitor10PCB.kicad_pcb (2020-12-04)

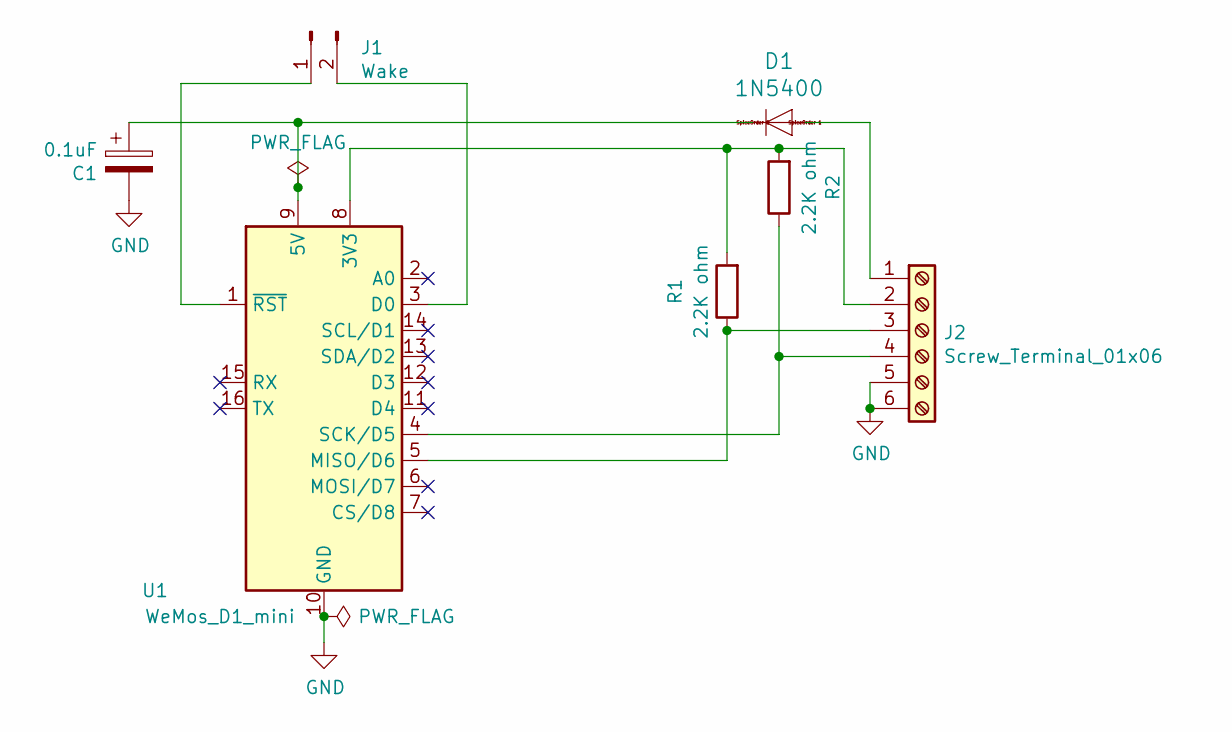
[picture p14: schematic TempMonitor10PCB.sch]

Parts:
C1: 0.1uF; C_Disc_D5.0mm_W2.5mm_P2.50mm
D1: 1N5400
J1: Wake; PinHeader_1x02_P2.54mm_Vertical
J2: Screw_Terminal_01x06; TerminalBlock_Phoenix_PT-1,5-6-5.0-H_1x06_P5.00mm_Horizontal
R1, R2: 2.2K ohm; R_Axial_DIN0207_L6.3mm_D2.5mm_P10.16mm_Horizontal
U1: WeMos_D1_mini; WEMOS_D1_mini_light

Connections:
GND: C1.2, J2.5, J2.6, U1.10 (GND)
unnamed: C1.1, D1.C, U1.9 (5V)
unnamed: D1.A, J2.1
unnamed: J1.1, U1.1 (~RST)
unnamed: J1.2, U1.3 (D0)
unnamed: J2.2, R1.2, R2.2, U1.8 (3V3)
unnamed: J2.3, R1.1, U1.5 (MISO/D6)
unnamed: J2.4, R2.1, U1.4 (SCK/D5)

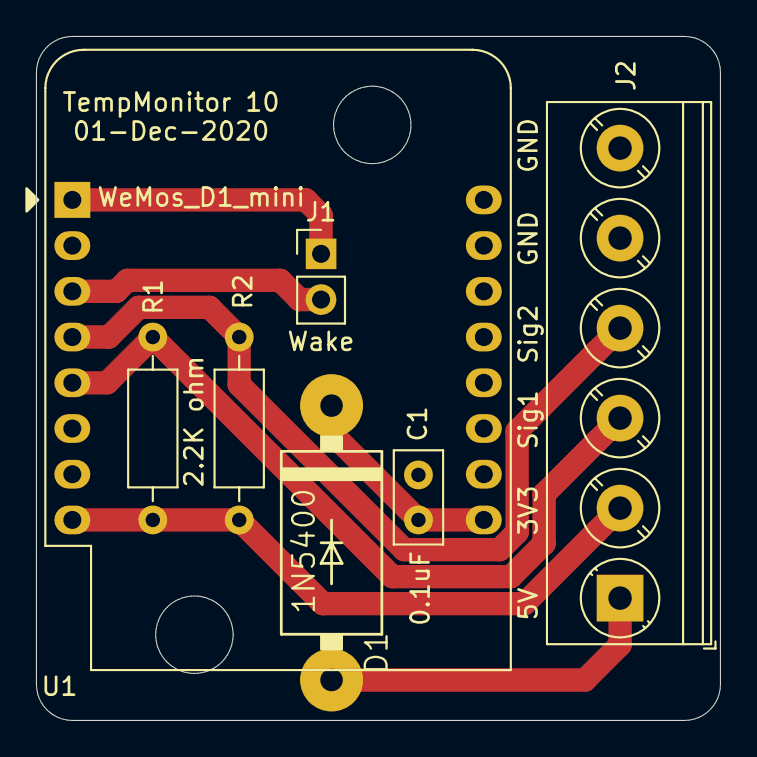
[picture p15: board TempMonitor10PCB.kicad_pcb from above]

Board: 2 copper layers, 38.0 x 38.0 mm, 7 parts (0 on the bottom side), 8 nets.

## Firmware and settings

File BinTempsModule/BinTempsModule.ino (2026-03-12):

// Bin temperature module
// Wemos D1 mini Pro, ESP 12F    board: LOLIN(Wemos) D1 R2 & mini  or NodeMCU 1.0 (ESP-12E Module)

// user data saved on the sensor:
// 16 bit data
// 11111111  1111  1111
// bin       cable sensor
// 0-255     0-15  0-15

#include <ESP8266WiFi.h>        // Arduino IDE 'Additional Board' http://arduino.esp8266.com/stable/package_esp8266com_index.json
#include <ESP8266WebServer.h>
#include <ESP8266mDNS.h>
#include <EEPROM.h>

#include <OneWire.h>            // https://github.com/PaulStoffregen/OneWire
#include <WiFiUdp.h>
#include <Wire.h>
#include "DS2482.h" 		    // https://github.com/paeaetech/paeae
#include "ESP2SOTA_RC.h"	// modified from https://github.com/pangodream/ESP2SOTA

# define InoDescription "BinTempsModule 12-Mar-2026"
#define InoID 12036         // firmware version — update with every build (DDMMY format)
#define StructVersion 1     // EEPROM layout version — increment ONLY when ModuleData fields change

#define SDApin  4
#define SCLpin  5

#define MaxSensors 200
const uint32_t SampleTime = 3600000;    // update temps every hour

struct ModuleData
{
	byte ID = 0;
	char Name[12] = "Module0";
	uint16_t Port = 1600;
	byte Pin1 = 5;  // D1
	byte Pin2 = 4;  // D2
	byte Pin3 = 14; // D5
	byte Pin4 = 12; // D6
	bool UseDS2482 = false;
	bool StrongPullup = false;
	byte PullupPin = 13;
};

ModuleData MDL;

struct ModuleNetwork
{
	uint16_t Identifier = 7654;
	char SSID[32] = "ssid";
	char Password[32] = "password";
	bool UseWifi = false;
};

ModuleNetwork MDLnetwork;

OneWire OWbus[] = { OneWire(MDL.Pin1),OneWire(MDL.Pin2), OneWire(MDL.Pin3),OneWire(MDL.Pin4) };
byte BusCount = 4;

DS2482 OneWireMaster(0);

struct SensorData
{
	byte ID[8];
	byte BusID;
	byte Temperature[2];	// msb [1], lsb [0]
	byte UserData[2];
};

SensorData Sensors[MaxSensors];

const long pulsewait = 90000;                       // time to wait for a heartbeat before attempting to reconnect (milliseconds)
unsigned long pulsetime = millis() - pulsewait;     // set expired on startup so WiFi connects immediately

unsigned long LoopTime;
WiFiUDP udp;
byte SensorCount = 0;

// Pending broadcast command — set when a moduleId=0 command arrives, executed after stagger delay
byte PendingCommand = 0;
unsigned long CommandSetTime = 0;
const uint32_t BroadcastStaggerMs = 60000UL;   // 1 minute per module ID
bool DS2842Connected = false;
ESP8266WebServer server(80);
uint32_t Readtime;
uint8_t MacAddr[6];

void setup()
{
	uint8_t ErrorCount;
	Serial.begin(38400);
	delay(5000);
	Serial.println();
	Serial.println();
	Serial.println(InoDescription);
	Serial.println();

	EEPROM.begin(256);

	int16_t StoredStructVersion;
	EEPROM.get(0, StoredStructVersion);
	if (StoredStructVersion == StructVersion)
	{
		Serial.println("Loading stored settings.");
		EEPROM.get(10, MDL);
	}
	else
	{
		Serial.println("ModuleData struct changed — resetting to defaults.");
		EEPROM.put(0, (int16_t)StructVersion);
		EEPROM.put(10, MDL);
		EEPROM.commit();
	}

	EEPROM.get(100, MDLnetwork);
	if (MDLnetwork.Identifier != 7654)
	{
		Serial.println("Network settings not found, using defaults.");
		MDLnetwork.Identifier = 7654;
		strncpy(MDLnetwork.SSID, "ssid", sizeof(MDLnetwork.SSID));
		strncpy(MDLnetwork.Password, "password", sizeof(MDLnetwork.Password));
		MDLnetwork.UseWifi = false;
		EEPROM.put(100, MDLnetwork);
		EEPROM.commit();
	}

	Serial.print("Module name: ");
	Serial.println(MDL.Name);

	Serial.print("Module ID: ");
	Serial.println(MDL.ID);

	// start with station mode off
	WiFi.disconnect(true);

	WiFi.macAddress(MacAddr);
	String AP = MDL.Name;
	AP += "  (";
	AP += WiFi.macAddress();
	AP += ")";
	WiFi.softAP(AP);

	Serial.print("Access Point name: ");
	Serial.println(AP);

	Serial.print("Settings Page IP: ");
	Serial.println(WiFi.softAPIP());

	// web server
	Serial.println();
	Serial.println("Starting Web Server");
	server.on("/", HandleRoot);
	server.on("/page1", HandleTemps);
	server.on("/page2", HandlePage2);
	server.on("/UpdateTemps", DoUpdate);
	server.onNotFound(HandleRoot);
	server.begin();

	// DS2482
	if (MDL.UseDS2482)
	{
		ErrorCount = 0;
		Serial.println("");
		Serial.println("Connecting to DS2482 One-Wire Master...");
		Wire.begin(SDApin, SCLpin);
		OneWireMaster.reset();

		while (!DS2842Connected)
		{
			//configure DS2482 to use active pull-up instead of pull-up resistor 
			DS2842Connected = OneWireMaster.configure(DS2482_CONFIG_APU);
			Serial.print(".");
			delay(500);
			if (ErrorCount++ > 10) break;
		}
		Serial.println("");
		if (DS2842Connected)
		{
			Serial.println("DS2482 found.");
		}
		else
		{
			Serial.println("DS2482 not found.");
		}
	}
	else
	{
		Serial.println("");
		Serial.println("DS2482 disabled.");
		Serial.println("Using GPIOs for signals.");
	}

	if (MDL.StrongPullup)
	{
		// provide 5V for DS2842 to use for strong pullup
		pinMode(MDL.PullupPin, OUTPUT);
		digitalWrite(MDL.PullupPin, HIGH);
	}

	// Stagger first read by 1 minute per module ID so modules don't all burst at once.
	// Module 1 reads immediately, module 2 reads after 1 min, module 3 after 2 min, etc.
	// After the first read each module runs on its own 1-hour cadence.
	uint32_t staggerMs = ((uint32_t)(MDL.ID - 1) * BroadcastStaggerMs) % SampleTime;
	Readtime = millis() - SampleTime + staggerMs;

	/* INITIALIZE ESP2SOTA LIBRARY */
	ESP2SOTA.begin(&server);
	Serial.println("");
	Serial.println("OTA started.");

	Serial.println("");
	Serial.println("Finished Setup");
	Serial.println("");
}

void loop()
{
	server.handleClient();

	if (MDLnetwork.UseWifi)
	{
		if (WiFi.status() == WL_CONNECTED)
		{
			ReceiveData();
		}

		if (millis() - pulsetime > pulsewait)
		{
			pulsetime = millis();
			if (WiFi.status() != WL_CONNECTED)
			{
				ConnectWifi();
			}
			else
			{
				SendModuleDescription();	// re-announce if WiFi ok but server went quiet
			}
		}
	}

	if (millis() - Readtime > SampleTime)
	{
		Readtime = millis();

		UpdateTemps();

		int Min = SampleTime / 60000;
		Serial.print("");
		Serial.print("Updating in ");
		Serial.print(Min);
		Serial.println(" minutes.");
	}

	if (PendingCommand != 0 && millis() - CommandSetTime >= (uint32_t)(MDL.ID - 1) * BroadcastStaggerMs)
	{
		byte cmd = PendingCommand;
		PendingCommand = 0;
		if ((cmd & 1) == 1) SendTemps();
		if ((cmd & 2) == 2) SendModuleDescription();
		if ((cmd & 4) == 4) { UpdateTemps(); SendTemps(); }
	}
}

bool GoodCRC(byte Data[], byte Length)
{
	byte ck = CRC(Data, Length - 1, 0);
	bool Result = (ck == Data[Length - 1]);
	return Result;
}

byte CRC(byte Chk[], byte Length, byte Start)
{
	byte Result = 0;
	for (int i = Start; i < Length; i++)
	{
		Result += Chk[i];
	}
	return Result;
}

void SaveData()
{
	EEPROM.put(0, (int16_t)StructVersion);
	EEPROM.put(10, MDL);
	EEPROM.put(100, MDLnetwork);
	EEPROM.commit();

	delay(3000);

	ESP.restart();
}


void UpdateTemps()
{
	if (DS2842Connected)
	{
		UpdateSensorsMaster();
	}
	else
	{
		UpdateSensors();
	}
}

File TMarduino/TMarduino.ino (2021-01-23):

// Wemos D1 mini Pro,  board: LOLIN(Wemos) D1 R2 & mini

#include <EEPROM.h>
#include <ESP8266WiFi.h>
#include <WiFiClient.h>
#include <ESP8266WebServer.h>

#include <OneWire.h>            // https://github.com/PaulStoffregen/OneWire
#include <WiFiUdp.h>
#include <ArduinoOTA.h>
#include <ESP8266mDNS.h>

//bool ForceWebPage = true;
bool ForceWebPage = false;

#define UseDS2482	1	// 0 don't use, 1 use

#define SDApin  12
#define SCLpin  14

int BusCount = 3;

#define AppName "Temperature Monitor"
#define AppVersion "23-Jan-2021"

#if UseDS2482

#include <Wire.h>
#include<DS2482.h>		// https://github.com/paeaetech/paeae
DS2482 OWbus(0);

#else

// Wemos D1 mini Pro
OneWire OWbus[] = { OneWire(12),OneWire(13),OneWire(14) };

#endif

ESP8266WebServer server(80);

extern "C"
{
#include "user_interface.h"		// for RTC memory access
}
#define RTCMEMORYSTART 65

// wifi
#define CommLength 17
byte OutBuffer[CommLength];	 // Array to send data back
byte InBuffer[255];	 //buffer to hold incoming packet
WiFiUDP UDP;
unsigned int ReceiveFromPort = 8120;      // local port to listen on

//sending back to where and which port
IPAddress ipDestination;
unsigned int SendToPort = 1688; //port that listens

byte CurrentSensorAddress[8];

// commands:
// 1 all sensor report
// 2 specific sensor report
// 3 set sensor userdata
byte CommandByte;

unsigned long CommTime;
unsigned long ConnectedCount = 0;
unsigned long ReconnectCount = 0;

int UserData;

byte SensorCount = 0;
bool SendEnabled = false; // if last PGN received was for this node send is enabled

struct SensorData
{
	byte ID[8];
	byte BusID;
	byte Temperature[2];	// msb [1], lsb [0]
	byte UserData[2];
};

SensorData Sensors[255];

struct ControlBoxData
{
	byte ID;	// unique to each control box
	char SSID[32];
	char Password[32];
	byte UseSleep;
	int SleepInterval;
	byte ControlBoxCount;
	byte Check;	// validity check
};

ControlBoxData BoxData;

struct WakeTimeData
{
	int MinutesRemaining;	// needs to be 4 bytes each for RTC memory
	int Check;
};

WakeTimeData WT;

int CurrentTime = 0;	// 0-1439 minutes (24 hrs)
unsigned long FlashTime;
bool FlashState;

unsigned int PGN;
int TimeSlot = 5;	// time (minutes) allocated to a controlbox to transmit data
bool ReceivedReply = false;
unsigned long UpdateTime;

byte LineUDS;
byte LineASR;
byte LineSensors;

unsigned long DiagTime;

bool SendDiag = false;
bool Restart = false;

void setup()
{
	Serial.begin(38400);
	delay(5000);

	Serial.println();
	Serial.print(AppName);
	Serial.print("  :  ");
	Serial.println(AppVersion);
	Serial.println();
	if (UseDS2482)
	{
		Serial.println("Using DS2482.");
	}
	else
	{
		Serial.println("Not using DS2482.");
	}
	Serial.println();

	pinMode(D0, WAKEUP_PULLUP);

	NetConnect();

	StartOTA();

	pinMode(LED_BUILTIN, OUTPUT);
	digitalWrite(LED_BUILTIN, HIGH);	// LED off

#if UseDS2482

	Serial.println();
	Wire.begin(SDApin, SCLpin);
	OWbus.reset();

	//configure DS2482 to use active pull-up instead of pull-up resistor 
	//configure returns 0 if it cannot find DS2482 connected 
	if (OWbus.configure(DS2482_CONFIG_APU))
	{
		Serial.println("DS2482 found.");
	}
	else
	{
		Serial.println("DS2482 not found.");
	}

#endif

	UpdateSensors();	// get an initial count of connected sensors
}

void loop()
{
	ArduinoOTA.handle();
	if (BoxData.UseSleep)
	{
		DoSleepMode();
	}
	else
	{
		DoClientMode();
	}

	if (SendDiag) SendDiagnostics();
	if (Restart) ESP.restart();
}

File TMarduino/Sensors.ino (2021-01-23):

#if !UseDS2482

// adapted from https://playground.arduino.cc/Learning/OneWire/

void UpdateSensors()
{
	byte Addr[8];
	byte Mem[2];
	SensorCount = 0;

	Serial.println();
	Serial.println("Updating sensors on " + String(BusCount) + " buses.");
	for (int i = 0; i < BusCount; i++)
	{
		Serial.println("Searching one-wire bus " + String(i));
		OWbus[i].reset_search();
		delay(500);
		while (OWbus[i].search(Addr) && SensorCount < 256)
		{
			LineSensors++;
			if (GetTemp(Addr, i, Mem))
			{
				for (int i = 0; i < 8; i++)
				{
					Sensors[SensorCount].ID[i] = Addr[i];
				}
				Sensors[SensorCount].BusID = i;
				Sensors[SensorCount].Temperature[0] = Mem[0];	// lsb
				Sensors[SensorCount].Temperature[1] = Mem[1];	// msb

				Sensors[SensorCount].UserData[0] = (byte)(UserData);		// lsb
				Sensors[SensorCount].UserData[1] = (byte)(UserData >> 8);	// msb	
				SensorCount++;
			}
			delay(500);
		}
	}
	Serial.println("Sensor count: " + String(SensorCount));
	LineUDS++;
}

bool GetTemp(byte Addr[], byte BusID,byte Mem[] )
{
	float Result = -127.0;
	UserData = 0;
	byte dsScratchPadMem[9];

	for (int i = 0; i < 3; i++)
	{
		OWbus[BusID].reset();
		OWbus[BusID].select(Addr);
		OWbus[BusID].write(0x44, 1);  // parasite power on

		delay(1000);
		OWbus[BusID].reset();
		OWbus[BusID].select(Addr);
		OWbus[BusID].write(0xBE);	// Issue read scratchpad cmd
		for (int i = 0; i < 9; i++)
		{
			dsScratchPadMem[i] = OWbus[BusID].read();
		}
		
		// check if valid frame
		if (OWbus[BusID].crc8(dsScratchPadMem, 8) == dsScratchPadMem[8])
		{
			Mem[1] = dsScratchPadMem[1];	// msb
			Mem[0] = dsScratchPadMem[0];	// lsb
			Result = (float)((int16_t)(Mem[1] << 8 | Mem[0]) / 16.0);	// twos complement conversion
			UserData = (dsScratchPadMem[2] << 8 | dsScratchPadMem[3]);
		}
		if (Result > -127) break;	// loop up to 3 times to get valid data
		delay(1000);
	}
	return (Result > -127);
}

void SetUserData(byte Addr[], byte BusID, int NewValue)
{
	OWbus[BusID].reset();
	OWbus[BusID].select(Addr);
	OWbus[BusID].write(0x4E, 1);	// begin write to scratchpad

	OWbus[BusID].write(NewValue >> 8, 1);
	OWbus[BusID].write(NewValue & 255, 1);
	OWbus[BusID].write(9, 1);		// set resolution to 0.5C
	delay(10);

	OWbus[BusID].reset();
	OWbus[BusID].select(Addr);

	OWbus[BusID].write(0x48, 1);	// copy scratchpad to eeprom
	delay(100);
}

void AllSensorsReport()
{
	if (SensorCount == 0)
	{
		// report no sensors
		SendData(0, 2);
	}
	else
	{
		// report available sensors
		bool Last;
		for (byte i = 0; i < SensorCount; i++)
		{
			Last = ((i + 1) == SensorCount);
			SendData(i, Last);
			delay(150);
		}
	}

	LineASR++;
}

void SingleSensorReport()
{
	for (byte i = 0; i < SensorCount; i++)
	{
		if (memcmp(Sensors[i].ID, CurrentSensorAddress, 8) == 0)
		{
			SendData(i, 1);
			break;	// exit loop
		}
	}
}

void SetNewUserData()
{
	for (byte i = 0; i < SensorCount; i++)
	{
		if (memcmp(Sensors[i].ID, CurrentSensorAddress, 8) == 0)
		{
			SetUserData(CurrentSensorAddress, Sensors[i].BusID, UserData);
			UpdateSensors(); // to update array
			break;	// exit loop
		}
	}
}
#endif

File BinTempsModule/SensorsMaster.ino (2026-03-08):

// adapted from https://playground.arduino.cc/Learning/OneWire/

void UpdateSensorsMaster()
{
	byte Addr[8];
	byte Mem[2];
	SensorCount = 0;
	int UserData = 0;

	Serial.println();
	Serial.println("Searching one-wire bus... ");
	OneWireMaster.wireResetSearch();
	delay(500);
	while (OneWireMaster.wireSearch(Addr) && SensorCount < 256)
	{
		if (GetTempMaster(Addr, Mem, UserData))
		{
			for (int i = 0; i < 8; i++)
			{
				Sensors[SensorCount].ID[i] = Addr[i];
			}
			Sensors[SensorCount].Temperature[0] = Mem[0];
			Sensors[SensorCount].Temperature[1] = Mem[1];

			Sensors[SensorCount].UserData[1] = (byte)(UserData >> 8);
			Sensors[SensorCount].UserData[0] = (byte)(UserData);
			SensorCount++;
		}
		delay(500);
		yield();
	}
	Serial.println("Sensor count: " + String(SensorCount));
}

bool GetTempMaster(byte Addr[], byte Mem[], int& UserData)
{
	delay(500);
	float Result = -127.0;
	byte dsScratchPadMem[9];

	for (int i = 0; i < 3; i++)
	{
		OneWireMaster.wireReset();
		OneWireMaster.wireSelect(Addr);
		OneWireMaster.wireWriteByte(0x44);

		delay(1000);
		OneWireMaster.wireReset();
		OneWireMaster.wireSelect(Addr);
		OneWireMaster.wireWriteByte(0xBE);	// Issue read scratchpad cmd
		for (int j = 0; j < 9; j++)
		{
			dsScratchPadMem[j] = OneWireMaster.wireReadByte();
		}

		// check if valid frame
		if (OneWireMaster.crc8(dsScratchPadMem, 8) == dsScratchPadMem[8])
		{
			Mem[1] = dsScratchPadMem[1];	// msb
			Mem[0] = dsScratchPadMem[0];	// lsb
			Result = (float)((int16_t)(Mem[1] << 8 | Mem[0]) / 16.0);	// twos complement conversion
			UserData = (dsScratchPadMem[2] << 8 | dsScratchPadMem[3]);
		}
		if (Result > -127) break;	// loop up to 3 times to get valid data
		delay(1000);
	}
	return (Result > -127);
}

void SetUserDataMaster(byte Addr[], int NewValue)
{
	delay(500);
	OneWireMaster.wireReset();
	OneWireMaster.wireSelect(Addr);
	OneWireMaster.wireWriteByte(0x4E);	// begin write to scratchpad

	OneWireMaster.wireWriteByte(NewValue >> 8);
	OneWireMaster.wireWriteByte(NewValue & 255);
	OneWireMaster.wireWriteByte(0x1F);		// set resolution to 0.5C
	delay(10);

	OneWireMaster.wireReset();
	OneWireMaster.wireSelect(Addr);

	OneWireMaster.wireWriteByte(0x48);	// copy scratchpad to eeprom
	delay(100);
}

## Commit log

2020-11-23 Updated files.
    [TempMon.xls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]
2020-11-27 Wemos D1 mini version
    [TempMon.xls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]
2020-11-28 fixed sensor setdata sub, added webpage
    [Sensors.ino, TMarduino.ino]
2020-12-04 design change due to magic smoke
    [TempMon.xls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]
2021-01-09 DS2482, Nano 33 version
    [TempMonitor8PCB-B_Cu.gbr, TempMonitor8PCB-B_Mask.gbr, TempMonitor8PCB-B_Paste.gbr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]
2021-01-10 fix sleep time calculation
    [Sleep.ino, TMarduino.ino, WifiComm.ino]
2021-01-16 DS2482, Wemos D1 mini version, to replace buggy Nano 33 wifi
    [Network.ino, OTA.ino, Sensors.ino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]
2021-01-21 added option for DS2482, reorganized files
    [TMS1-B_Cu.gbr, TMS1-B_Mask.gbr, TMS1-B_Paste.gbr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]
2023-08-11 update folders
    [TMS1-B_Cu.gbr, TMS1-B_Mask.gbr, TMS1-B_Paste.gbr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]
2023-08-12 update folders, fix webpage temps
    [TMS1-B_Cu.gbr, TMS1-B_Mask.gbr, TMS1-B_Paste.gbr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]
2023-11-13 TM13 pcb
    [TM13.kicad_pcb, TM13.kicad_sch]
2023-11-14 fix timer loop
2023-11-15 no auto reconnect, trim webserver input
    [TM13.kicad_pcb, TM13.kicad_sch]
2023-11-21 move old files
    [TMS1-B_Cu.gbr, TMS1-B_Mask.gbr, TMS1-B_Paste.gbr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]
2023-11-24 update pcb
    [BOM-TM13.csv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]
2024-07-24 prevent unresponsive web page
    [Comm.ino]
2026-03-08 New version
    [BOM-TM13.csv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]
2026-03-09 temperature app
2026-03-10 fix convert sensor data
2026-03-10 add button
2026-03-10 Simplify README description of Temperature Monitor
    Removed redundant information about controlbox operation and power sources.
2026-03-12 update web page, change temp button function
2026-03-12 Discover button
2026-03-14 print graph, change database locking
